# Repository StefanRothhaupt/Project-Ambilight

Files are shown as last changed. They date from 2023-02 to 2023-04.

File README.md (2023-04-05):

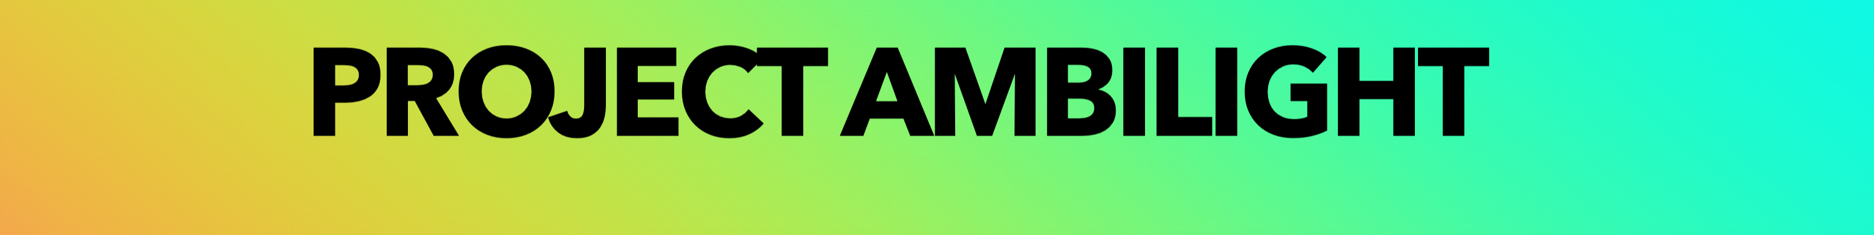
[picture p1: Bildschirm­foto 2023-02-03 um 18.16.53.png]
title foto of the project, with project name and fictive company name


## Description:
In the 6th semester of electrical engineering and information technology, students are supposed to envision and build their own product.
In this project students from the [University of Applied Sciences](https://ee.hm.edu) in Munich built a ambient light for a monitor.
The [ambient light](https://en.wikipedia.org/wiki/Bias_lighting) enhances the viewing experience by illuminating the surrounding environment, creating a more immersive and enjoyable atmosphere. The code and PCB were both designed and built in-house, demonstrating the team's technical abilities and attention to detail. The purpose of the project is to simulate the whole project cycle of developing and testing the product. 
We utilized the latest technology to read in the video stream, scale it down and cut it into sectors. The sectors were then analyzed to determine their most dominant color, which was then passed on to the LEDs on the back of the monitor. The result was a seamless and dynamic integration of light and video, creating an immersive viewing experience. The project required a high level of technical expertise and collaboration between the team members. This collaboration was enabled through scrum and state-of the art collaboration software like github and microsoft office.

## Resource Overview:
Here you can find all the relevant products we used (Find code, pcb-gerber-files, and the documentation below):
| Produkt | Quantity | estimated cost  |
| --- |:---:| -----:|
| [LED Strip, WS2812B, 5M 150LEDs](https://www.amazon.de/BTF-LIGHTING-WS2812B-adressierbare-Streifen-Wasserdicht/dp/B01CDTECSG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)  | 1| `30€` |
| [Raspberry Pi](https://www.raspberrypi.com/products/raspberry-pi-4-model-b/) | 1 | `120€` |
| [HDMI Splitter](https://www.amazon.de/Links-4330119358-HDMI-Adapter/dp/B0732MD43P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) | 1 | `17€` |
| [Capture Card](https://www.amazon.de/Newhope-Capture-Directly-Computer-Compatible-Schwarz/dp/B09NQM16VY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) | 1 | `18€` |
| [Powersupply](https://www.amazon.de/ALITOVE-Konverter-Transformator-Pixelstreifen-Sicherheitssystem-Black/dp/B0B49TZQZX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ÅMÅŽÕÑ&crid=1M5ERXVVCWK9A&keywords=5v+5a+netzteil&qid=1666264450&qu=eyJxc2MiOiI0LjE5IiwicXNhIjoiNC4wMSIsInFzcCI6IjQuMDAifQ%3D%3D&sprefix=5v+5a+netzteil%2Caps%2C140&sr=8-8) | 1 | `12€` |
| [SD card](https://www.amazon.de/SanDisk-microSD-Karte-VR-Spielgrafiken-4K-UHD-Video-SDSQXAF-032G-GN6GN/dp/B089M5KV4Y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) | 1 | `10€` |
| [Switch](https://www.amazon.de/Gebildet-Edelstahl-Drucktastenschalter-Wasserdichter-Kippschalter/dp/B07RXX75KZ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ÅMÅŽÕÑ&crid=1I6LW9XT2VN0S&keywords=schalter%2B5v%2B5a&qid=1666264741&qu=eyJxc2MiOiIyLjc3IiwicXNhIjoiMC4wMCIsInFzcCI6IjAuMDAifQ%3D%3D&sprefix=schalter%2B5v%2B5a%2Caps%2C67&sr=8-13&th=1 ) | 1 | `10€` |

## User-guide:
Follow the [instructions](https://github.com/StefanRothhaupt/Project-Ambilight/blob/main/4-Documentation/User_Manual.pdf), to setup the ambient light if you have the Raspberry Pi with a preinstalled OS and ambilight.py program.
If you still need to setup the Raspberry Pi please follow the instructions below.

## Developer Documentation:
Follow the steps in the [Software manual](https://github.com/StefanRothhaupt/Project-Ambilight/blob/main/4-Documentation/Projekt_Ambilight_Software_Manual.pdf) to setup your [Raspberry Pi](https://www.raspberrypi.com/products/raspberry-pi-4-model-b/) for the ambient light. Download the [ambilight python code](https://github.com/StefanRothhaupt/Project-Ambilight/blob/main/1-Code/ambilight.py). Keep in mind, that you need at least 4GB of RAM to drive the capture card. Otherwise the imageprocessing will be too slow and you will be notice a delay when the colors of the LEDs need to change quickly.
After the software setup, follow the [Hardware manual](https://github.com/StefanRothhaupt/Project-Ambilight/blob/main/4-Documentation/Projekt_Ambilight_Hardware_Manual.pdf) to make the system more compact and ready to ba packed into the housing.
You can use [our design](https://github.com/StefanRothhaupt/Project-Ambilight/tree/main/3-Case) or you can create your own.

## Demo-video (COMING SOON):
In this demo video we briefly go over the program and how it works and we give you a glimpse of what the ambilight is capable of.
Pitch-video_of_the_project (https://www.youtube.com)

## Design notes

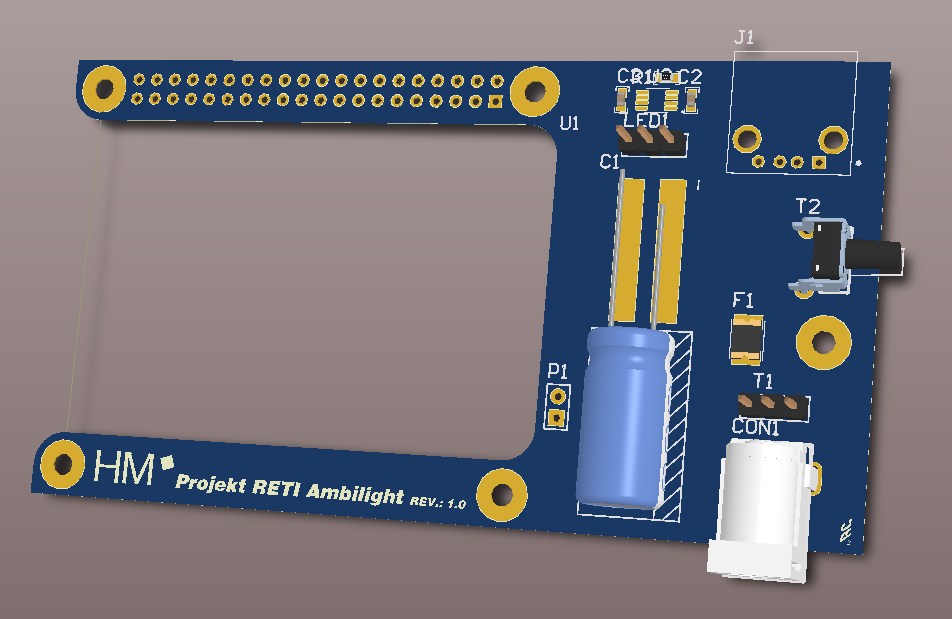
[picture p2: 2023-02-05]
2-PCB/Project Outputs for HM_RETI_Ambilight_v1_0/HM_RETI_Ambilight_PCB.png

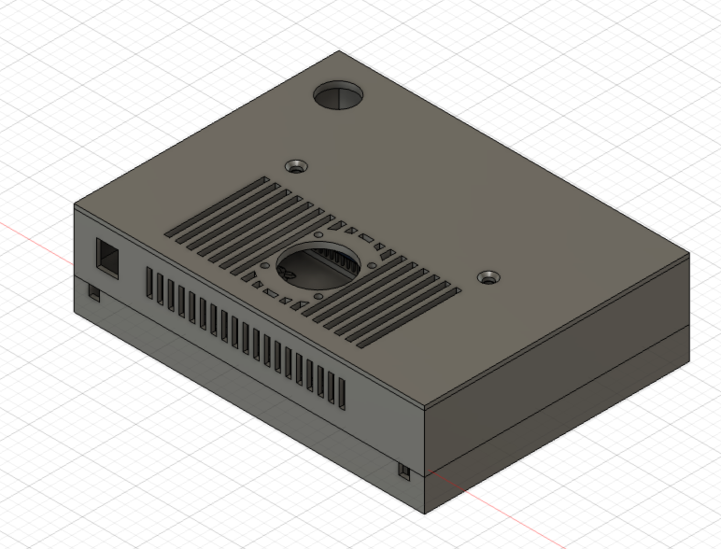
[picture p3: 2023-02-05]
3-Case/HM_RETI_Ambilight_Case.png

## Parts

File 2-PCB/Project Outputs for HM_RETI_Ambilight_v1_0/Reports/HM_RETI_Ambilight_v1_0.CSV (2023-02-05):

Bill of Material for
On 05/02/2023 at 21:14:32
Comment | Pattern | Quantity | Components
1000uF | C_10mm_left | 1 | C1 | C, SMD, ELKO, 6,5V, ± 10%
100nF | C_0603 | 2 | C2, C3 | C, SMD, MLCC, 25V, ± 10%
1k | R_0603 | 1 | R1 | R, SMD, Chip, 100mW, ± 1%
DC 12V Power BUCHSE | DC_BUCHSE_LUMBERG_2_35mm_STIFT | 1 | CON1 | DC_BUCHSE_LUMBERG_2_35mm_STIFT
Fuse for RPI | FUSER_MF-MSMF250/16X-2 | 1 | F1 | Polymeric PTC Resettable Fuse 16V 2.5 A Ih Surface Mount 1812 (4532 Metric), Concave
Fuse for USB Power | FUSER_MF-MSMF250/16X-2 | 1 | F2 | Polymeric PTC Resettable Fuse 16V 1.1 A Ih Surface Mount 1812 (4532 Metric), Concave
Pin Header 2x1 | Header 2x1 | 1 | P1 | Board-to-Board-Steckverbinder, vertikal, 2.54 mm, 2 Kontakt(e), Stiftleiste, Baureihe WR-PHD
Pin Header 3x1 | Header 3x1 | 1 | T1 | Board-to-Board-Steckverbinder, vertikal, 2.54 mm, 3 Kontakt(e), Stiftleiste, Baureihe WR-PHD
Pin Header for LEDs | Header 3x1 | 1 | LED1 | Board-to-Board-Steckverbinder, vertikal, 2.54 mm, 3 Kontakt(e), Stiftleiste, Baureihe WR-PHD
Raspbarry Pi4 | MODULE_RASPBERRY_PI_3_MODEL_B+ | 1 | U1 | BCM2835 Raspberry Pi Model B+ - ARM11, VideoCore MPU Embedded Evaluation Board
Reset Taster RPI | 431256058736 | 1 | T2 | Taster, THT, 90°, 8,35mm, black
TXS0102DCTT / Level Shifter | SOP65P400X130-8N | 1 | U2 | 2-Bit Bidirectional Voltage-Level Shifter for Open-Drain and Push-Pull Application
USB Power Output | CUI_UJ2-AH-4-TH | 1 | J1 | Type A, USB 2.0, 1 A, Right Angle, Through Hole, USB Receptacle

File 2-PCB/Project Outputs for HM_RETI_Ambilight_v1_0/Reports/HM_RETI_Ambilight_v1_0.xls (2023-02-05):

Comment | Description | Designator | Footprint | Quantity | Hersteller#
1000uF | C, SMD, ELKO, 6,5V, ± 10% | C1 | C_10mm_left | 1
100nF | C, SMD, MLCC, 25V, ± 10% | C2, C3 | C_0603 | 2
DC 12V Power BUCHSE | DC_BUCHSE_LUMBERG_2_35mm_STIFT | CON1 | DC_BUCHSE_LUMBERG_2_35mm_STIFT | 1
Fuse for RPI | Polymeric PTC Resettable Fuse 16V 2.5 A Ih Surface Mount 1812 (4532 Metric), Concave | F1 | FUSER_MF-MSMF250/16X-2 | 1
Fuse for USB Power | Polymeric PTC Resettable Fuse 16V 1.1 A Ih Surface Mount 1812 (4532 Metric), Concave | F2 | FUSER_MF-MSMF250/16X-2 | 1
USB Power Output | Type A, USB 2.0, 1 A, Right Angle, Through Hole, USB Receptacle | J1 | CUI_UJ2-AH-4-TH | 1
Pin Header for LEDs | Board-to-Board-Steckverbinder, vertikal, 2.54 mm, 3 Kontakt(e), Stiftleiste, Baureihe WR-PHD | LED1 | Header 3x1 | 1
Pin Header 2x1 | Board-to-Board-Steckverbinder, vertikal, 2.54 mm, 2 Kontakt(e), Stiftleiste, Baureihe WR-PHD | P1 | Header 2x1 | 1
1k | R, SMD, Chip, 100mW, ± 1% | R1 | R_0603 | 1
Pin Header 3x1 | Board-to-Board-Steckverbinder, vertikal, 2.54 mm, 3 Kontakt(e), Stiftleiste, Baureihe WR-PHD | T1 | Header 3x1 | 1
Reset Taster RPI | Taster, THT, 90°, 8,35mm, black | T2 | 431256058736 | 1 | 431256083716
Raspbarry Pi4 | BCM2835 Raspberry Pi Model B+ - ARM11, VideoCore MPU Embedded Evaluation Board | U1 | MODULE_RASPBERRY_PI_3_MODEL_B+ | 1
TXS0102DCTT / Level Shifter | 2-Bit Bidirectional Voltage-Level Shifter for Open-Drain and Push-Pull Application | U2 | SOP65P400X130-8N | 1

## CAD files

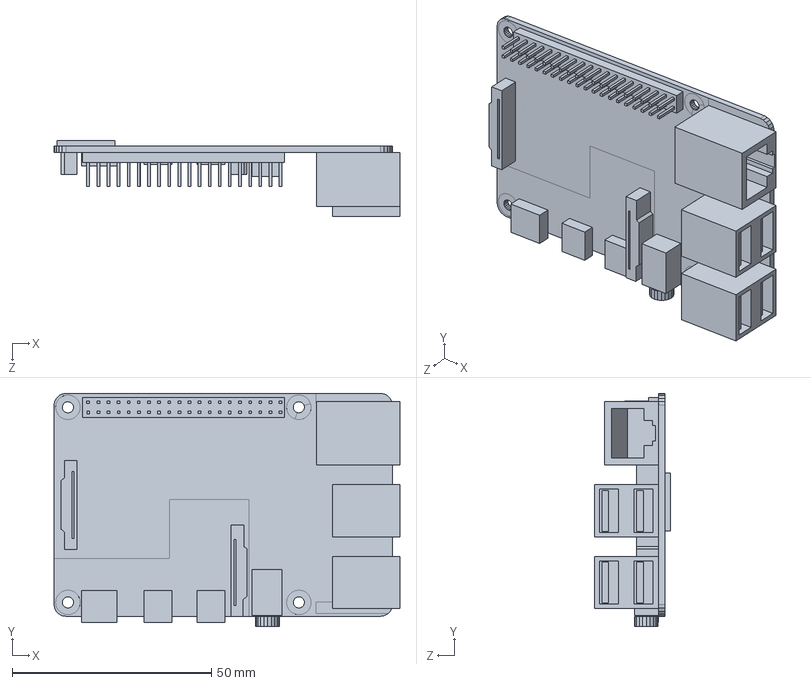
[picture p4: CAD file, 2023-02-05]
2-PCB/Project Outputs for HM_RETI_Ambilight_v1_0/ExportSTEP/Raspberry_Pi_4_B.STEP
86.9 x 58.6 x 19.0 mm

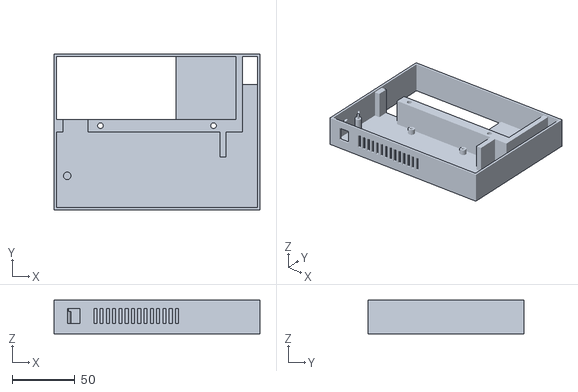
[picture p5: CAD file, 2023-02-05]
3-Case/HM_RETI_Ambilight_Case_Mid.stl
164.0 x 124.0 x 27.0

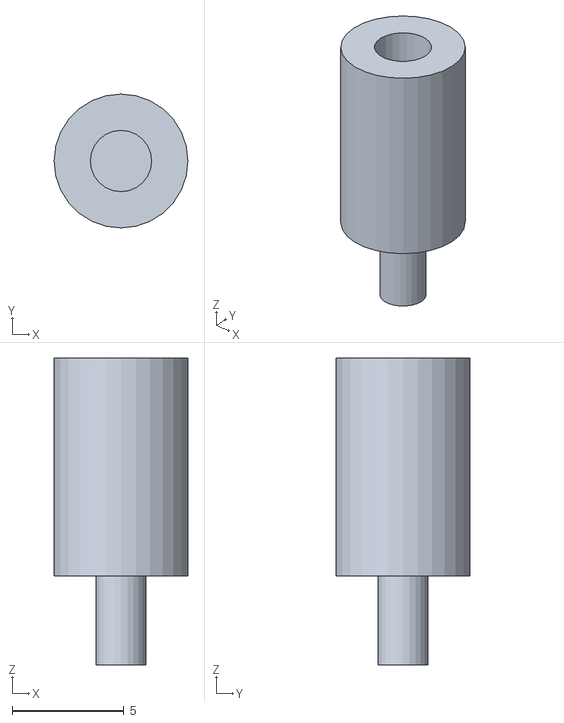
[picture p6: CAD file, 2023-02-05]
3-Case/HM_RETI_Ambilight_Case_Spacer1.stl
6.00 x 6.00 x 13.8

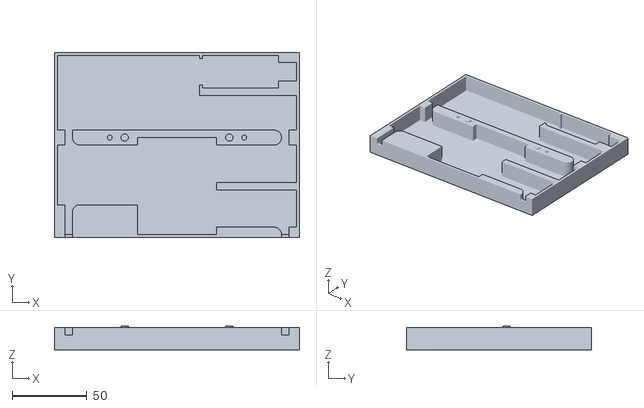
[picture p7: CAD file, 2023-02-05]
3-Case/HM_RETI_Ambilight_Case_Bottom.stl
164.0 x 124.0 x 16.0

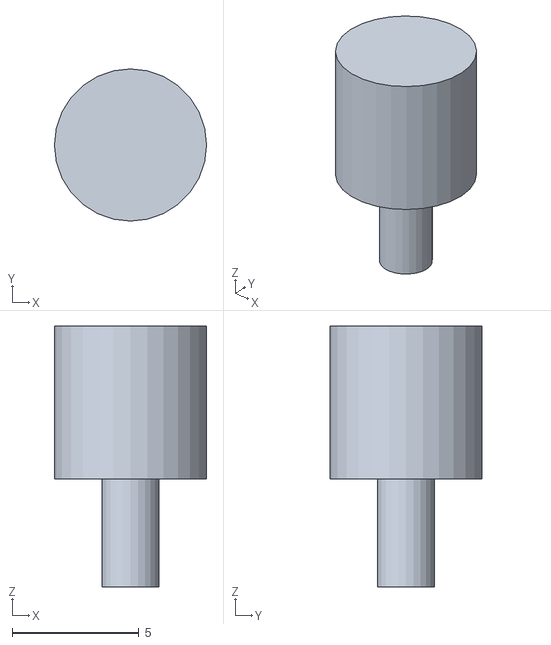
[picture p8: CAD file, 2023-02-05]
3-Case/HM_RETI_Ambilight_Case_Spacer2.stl
6.00 x 6.00 x 10.3

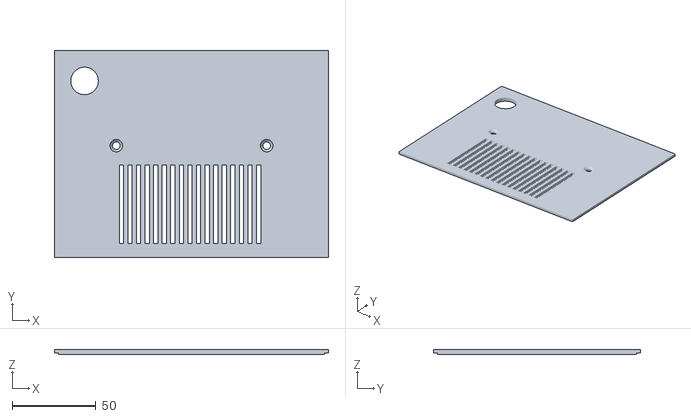
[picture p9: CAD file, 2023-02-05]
3-Case/HM_RETI_Ambilight_Case_Top.stl
164.0 x 124.0 x 3.00

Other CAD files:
3-Case/HM_RETI_Ambilight_Case.f3z

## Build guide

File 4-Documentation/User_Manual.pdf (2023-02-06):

# User Manual

Marco Bertsch

3. Februar 2023

## Inhaltsverzeichnis

1 Introduction | 2
2 Commissioning | 2
2.1 Adhere LED strip | | 2
2.2 Connect HDMI cable | | 2
2.3 Start Raspberry Pi | | 2
3 Operation | 2
4 Problem solving | 2
4.1 HDMI input is not recognized | | 2

1

## 1 Introduction

The ambient light is a lighting on the back of the television that projects the colors of the screen onto the wall, enhancing the movie experience.
As electrical engineering students at the Munich University of Applied Sciences, we developed a solution for the above concept as part of a project work. An external device processes the television’s image information and generates the color information for the background lighting from it.

## 2 Commissioning

### 2.1 Adhere LED strip

To put the device into operation, you must first attach the LED strips to the sides of the TV/monitor. The number of LEDs to be mounted vertically and horizontally are already replaced in the right place with flexible wires, which should represent the corners.
It is important to make sure that you start in the bottom right corner (screen viewed from the front) and from there, counterclockwise, attach the LEDs.

### 2.2 Connect HDMI cable

Connect the HDMI cable to the desired video output device.

### 2.3 Start Raspberry Pi

To start the raspberry pi you only need to connect the power supply and the raspberry pi will boot automatically.

## 3 Operation

To operate the device you only need to connect it to the power supply. The connected HDMI device is automatically detected and the LEDs start to adapt to the screen.

## 4 Problem solving

### 4.1 HDMI input is not recognized

If the external video signal is not detected you have to reboot the Pi again. To do this, simply disconnect the power supply and then reconnect it.

2

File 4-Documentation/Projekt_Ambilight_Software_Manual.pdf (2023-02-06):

1

# Projekt Ambilight

2

# Software Manual Projekt Ambilight Hochschule München

## Inhalt

1. Software Installation
1.1 Betriebssystem
1.2 Python
1.3 Bibliotheken
2. Implementierung
2.1 Programmcode
2.2 Autostart
3. Beschreibung des Codes
3.1 Bildverarbeitung
3.2 Funktionen
3.3 Einstellmöglichkeiten

3

1. Software Installation
1.1 Betriebssystem
Als Betriebssystem wird Raspbian genutzt.
Bitte folgen Sie der Installationsanleitung der Entwicklerseite: https://www.raspberrypi.com/software/
1.2 Python
Überprüfen Sie, ob Python 3 auf Raspbian bereits installiert ist, indem Sie folgenden Befehl in die Konsole eingeben:

Dies sollte standardmäßig der Fall sein. Falls dem nicht so ist, laden Sie Python 3.7 unter folgender Adresse herunter: https://www.python.org/downloads/

1.3 Bibliotheken
1.3.1 | Open CV2
| Für die Installation von Open CV nutzen Sie bitte folgende Anweisungen:
| https://raspberrypi-guide.github.io/programming/install- opencv
1.3.2 | NeoPixels von Adafruit
| Installieren Sie die Bibliothek NeoPixels indem Sie folgende Befehle in die Konsole eingeben:

4

pip3 install adafruit-circuitpython-neopixel
Weitere Informationen finden Sie unter: https://github.com/adafruit/Adafruit_CircuitPython_NeoPixel
2. Implementierung
2.1 Programmcode
Um das Programm zu nutzen muss dieses in python3 geöffnet werden. Dazu können Sie den Code unter folgendem Link downloaden: https://github.com/StefanRothhaupt/Project-Ambilight/blob/main/1-Code/ambilight.py

Speichern sie das Programm unter /home/ambilight.py ab.
2.2 Autostart
Um das Programm mit dem Hochfahren des Raspberry Pi zu starten müssen folgende Schritte befolgt werden:
Geben Sie in die Konsole den Befehl:
sudo nano /etc/rc.local
ein. Öffnen Sie die Datei “rc.local“ fügen Sie vor “exit 0“ folgendes ein: python3 /home/ambilight.py &
Speichern Sie die Datei indem Sie “Strg +O“ drücken.
Geben sie in der Konsole
sudo reboot
ein, um einen Neustart auszuführen.

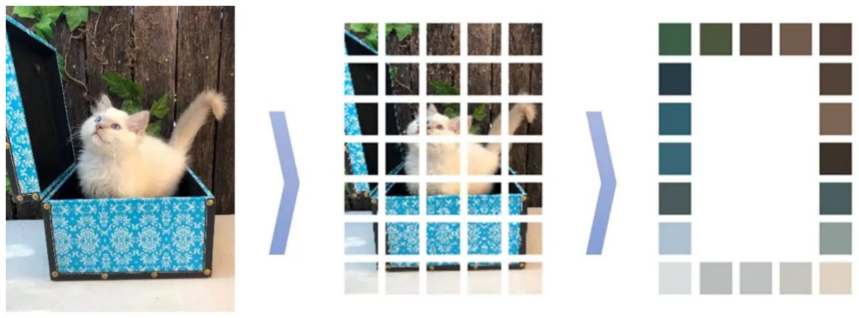
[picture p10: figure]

5

3. Beschreibung des Codes
3.1 Bildverarbeitung

Vom Videograbber werden in regelmäßigen Abständen Bilder angefordert. Diese werden segmentiert. Anschließend wird aus den äußeren Bildsegmenten die dominante Farbe ausgelesen, die inneren Segmente werden nicht weiterverarbeitet. Die Farbinformationen werden an die jeweiligen LEDs weitergegeben.
3.2 Funktionen
3.2.1 | get_avg_color
| In dieser Funktion werden die dominanten Farben in den Bildsegmenten ermittelt
3.2.2 | get_sectors
| In dieser Funktion wird das Bild in Sektoren unterteilt und speichert die dominante Farbe, die durch die Funktion get_avg_color bestimmt wird in eine Liste.
3.2.3 | start_up_color
| Diese Funktion wird beim Start des Programms ausgeführt und sorgt für die Start-Animation.

6

3.2.4 capture_init
Mithilfe dieser Funktion wird der Port der Capture Card bestimmt und zurückgegeben.
3.3 Einstellmöglichkeiten
3.3.1 Anzahl der Segmente pro Seite Mithilfe der beiden Variablen “x_pixel“ und “y_pixel“ können die Anzahl der Segmente an den Seiten festgelegt werden. Dies dient zur korrekten Einstellung der LEDs entsprechend ihrer Anzahlsowie ihrer Position an den Bildschirmseiten. Dabei ist zu beachten, dass die Anzahl an Segmenten pro Seite der Anzahl an LEDs pro Seite entspricht.
3.3.2 Resize
Über die Funktion “cv2.resize“ kann die Bildgröße verändert werden. Diese wird genutzt um Rechenaufwand zu sparen.
Kleinere | Parameter | sorgen | für | einen | schnelleren
Programmablauf und somit für ein bessere Nutzung des Ambilight.

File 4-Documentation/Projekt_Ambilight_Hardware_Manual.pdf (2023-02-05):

# Hardware Manual

Bastian Gruber

February 5, 2023

## Contents

1 Introduction | 2
2 Components | 2
3 Assembly | 3

## 1 Introduction

The following user manual contains all important information about design decisions and component selection for the Ambilight project. In the subsequent part, all components are listed individually with relevant information. In the last section you will find a setup plan for the complete system.

## 2 Components

### 2.1 Raspbarry Pi 4

The RaspbarryPi 4 is used as the single board computer. Minimum requirement for the RAM is 4GB. This demand is based on the used capture card. If you use a different capture card than recommended, you can also use another model of the Raspbarry Pi family that supports the requirements of the capture card. As memory card for the operating system we recommend a SD card class 10 or higher. This ensures the shortest possible boot sequence.

### 2.2 Capture card

When selecting the capture card, you should mainly pay attention to the maximum desired frame rate. In our case 60FPS. Another important point is the system requirements for the single-board computer. For example, the recommended capture card requires 4GB of RAM. Make sure that this system requirement is met.

### 2.3 HDMI splitter

When choosing the HDMI splitter, pay attention to the maximum desired picture quality on the screen. The splitter must be able to pass this quality from the input to the output. Likewise, a power supply via 5V USB should be considered, since this is provided by the specific PCB.

### 2.4 HDMI cables

3 HDMI cables are required for the complete system. Input, output to the TV, and output to the capture card. The lengths of the cables can be freely selected as desired. For the output cable to the capture card, we recommend a 0.25m cable so that everything fits into the housing. Again, the maximum desired picture quality must be taken into account.

### 2.5 LED strip

The LEDs used are from the well-known WS2812 series. They are easy and cheap to get and can be easily controlled via software library. The length of the LED strip can be freely adjusted to the TV size. Also the number of LEDs per section can be adjusted as desired. The larger the number, the better the color gradient. However, with the recommended 30LEDs / meter can already achieve a very good result.

### 2.6 Power supply

A 5V power supply with standard DC plug is required as power supply. It is important that the voltage carrying part of the plug is on the inside. (mostly standard). The minimum requirement for the provided current depends on the number of LEDs. A rough estimate can be calculated with the following formula: Imin = 2.5A + 20mA ∗ number of LEDs

### 2.7 Power switch

When selecting the on/off switch, attention must be paid to both the maximum voltage and current compatibility and the mode of operation. The switch must be applicable for 5V DC and must be able to switch the maximum current of the powersupply. As a mode of operation we need a switch that keeps its position. (so no push button)

### 2.8 Custom PCB

In order to have the least possible cabling effort, a custom PCB was developed for the project. This mainly provides the power supply for all components (Raspbarry Pi, HDMI splitter, LEDs). Also the conversion of the data signal (3V3) from the Raspbarry Pi to a higher level, which is understood by the LEDs (5V), is done here. For this task a 2-channel level shifter from TexasInstruments is installed. The PCB was designed with the software Altium Designer 15, for which all production and development data is available. During the production of the PCB the following features are considered:

- Format: 104.07mmx57.47mm
- Material: FR4 1.55mm 35µm Cu
- Surface finish: chemical Gold ENIG (HAL lead-free would be sufficient but harder to solder by hand)
- Board outline layer: Mechanical1

### 2.9 Enclosure

The enclosure was designed for the recommended components using the Autodesk Fusion 360 program. It consists of 3 layers held together with two self-tapping screws. The bottom layer contains the HDMI splitter, as well as the capture card. The HDMI cables also find their place here. The middle layer holds the Raspbarry Pi including the specific PCB. Last but not least, the case is closed with a lid. Here there is the possibility to integrate an optional 25mm fan.

## 3 Assembly

1. Connect the input HDMI cable to the input of the HDMI splitter.
2. Connect the output HDMI cable to the output 1 of the HDMI splitter.
3. Connect the HDMI cable to the video grabber with output 2 on the HDMI splitter.
4. Connect the HDMI cable to output 2 to the input of the video grabber.
5. Put the custom PCB in front of you in the orientation of the picture below.
6. Connect the Raspbarry Pi with the backside facing up to the connector A on the custom PCB. Hereby the USB ports face to the left.
7. (optional) Connect the reset button pins of the Raspbarry Pi to connector F of the custom board.
8. Plug the USB connector of the video grabber to one of the USB 3.0 ports of the Raspbarry Pi.
9. Connect the USB power supply cable of the HDMI splitter to connector C of the custom board.
10. Connect the On/Off switch to connector D of the custom board. The switch must be connected between the left two pins and the right pin. (optional) If you don’t want to use a switch you have to bridge all pins of connector D.
11. Connect the LEDs to connector B of the custom board. The left pin carries the 5V supply voltage, the middle pin carries the data and the right pin is the ground potential.
12. Connect the power supply to connector E of the custom board.

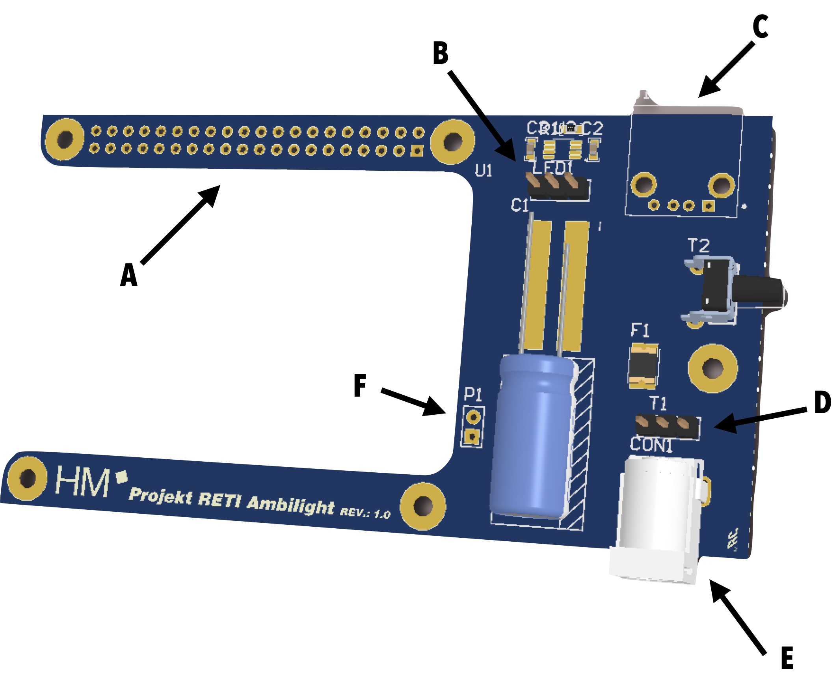
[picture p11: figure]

Figure 1: Custom PCB

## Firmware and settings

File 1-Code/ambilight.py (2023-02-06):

import board
import neopixel
import cv2
import numpy as np
import re
import time
x_pixel = 18
y_pixel = 10
pixel_pin = board.D18

num_pixels = (2*x_pixel+2*y_pixel) 
off = (0, 0, 0)
ORDER = neopixel.GRB
pixels = neopixel.NeoPixel(pixel_pin, num_pixels, brightness=0.3, auto_write=False, pixel_order=ORDER)
pixels.fill(off)
pixels.show()
    
    
def get_avg_color(sec):
        color = [0,0,0]
        img = sec
        
        #cv2.imshow(key, img) #zur kontrolle der sektoren
        img = cv2.cvtColor(src=img, code=cv2.COLOR_BGR2RGB)
        n_colors = 1
        criteria = (cv2.TERM_CRITERIA_EPS + cv2.TERM_CRITERIA_MAX_ITER, 200, .1)
        flags = cv2.KMEANS_RANDOM_CENTERS
        pixels = np.float32(img.reshape(-1, 3))
        _, labels, palette = cv2.kmeans(pixels, n_colors, None, criteria, 10, flags)
        _, counts = np.unique(labels, return_counts=True)
        indices = np.argsort(counts)[::-1]   
        freqs = np.cumsum(np.hstack([[0], counts[indices]/float(counts.sum())]))
        rows = np.int_(img.shape[0]*freqs)
        dom_patch = np.zeros(shape=img.shape, dtype=np.uint8)    
        for i in range(len(rows) - 1):
            dom_patch[rows[i]:rows[i + 1], :, :] += np.uint8(palette[indices[i]])
        #print("test")
        #print(dom_patch[0][0])
        color[0] = int(dom_patch[0][0][0])
        color[1] = int(dom_patch[0][0][1])
        color[2] = int((dom_patch[0][0][2])*0.7)
        #for m in len(dom_patch[0][0]):
        #    color[m] = dom_patch[0][0]
        #print(type(color))
        #print(type(color[0]))
        
        
        """
        #ploted die dominanten farben in python, macht es langsam
        fig, (ax1) = plt.subplots(1, 1, figsize=(12,6))
        ax1.imshow(dom_patch)
        ax1.set_title(key)
        ax1.axis('off')
        plt.show()
        """
        color = tuple(color)
        return color

def get_sectors(x, y, img):
    
    img_y, img_x, channels = img.shape
    
    x_width = img_x//x
    y_width = img_y//y
    colors = np.empty((2*x+2*y), dtype=object)
    faktor = 3
    
    for i in range(y):
        sec = img[img_y-(y_width*(i+1)):img_y-(y_width*(i)) , img_x-x_width//faktor:img_x]
        colors[i] = get_avg_color(sec)
        
        sec = img[0+(y_width*(i)):0+(y_width*(i+1)) , 0:x_width//faktor]
        colors[i+x+y] = get_avg_color(sec)
    
    for i in range(x):
        sec = img[0:y_width//faktor , img_x-(x_width*(i+1)):img_x-(x_width*(i))]
        colors[i+y] = get_avg_color(sec)
        
        sec = img[img_y-y_width//faktor:img_y , 0+(x_width*(i)):0+(x_width*(i+1))]
        colors[i+x+2*y] = get_avg_color(sec)
    
    return colors

def start_up_color():
    
    for i in range(num_pixels):
        pixels[i] = (0,255,0)
        pixels.show()
        time.sleep(0.03)
    time.sleep(1)
    
def capture_init():

    vidcap = cv2.VideoCapture(0)
    print("Test 0")
    success, image = vidcap.read()
    if success:
        pass
    else:
        vidcap.release()
        vidcap = cv2.VideoCapture(1)
        print("Test 1")
        success, image = vidcap.read()
        if success:
            pass
        else:
            vidcap.release()
            print("Test 2")
            vidcap = cv2.VideoCapture(2)
            
    return vidcap
    
    
#starting signal
start_up_color()
#get input stream
vidcap = cv2.VideoCapture(0)
success, image = vidcap.read()
#show ambilight
try:
    while 1:
        success, image = vidcap.read()
        image = cv2.resize(image, (180, 100), interpolation = cv2.INTER_NEAREST)
        
        if success:
            col = get_sectors(18, 10, image)

            for i in range(len(col)):
                pixels[i] = col[i]
                    
        pixels.show()

except KeyboardInterrupt:
    vidcap.release()
    pixels.fill(off)
    pixels.show()
    exit

exit
